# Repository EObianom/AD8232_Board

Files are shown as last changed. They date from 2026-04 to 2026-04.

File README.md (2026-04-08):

# AD8232_Board
AD8232 Mini ECG Breakout Board

A compact, production-ready ECG front-end built around the AD8232, designed for seamless integration into wearable and embedded systems.

Small in size, deliberate in design, and ready to manufacture.



## Overview

This project implements a highly miniaturised ECG acquisition circuit with a footprint of just 25mm × 17.7mm. It is engineered for space-constrained applications where traditional breakout boards fall short. Unlike conventional AD8232 modules, this design eliminates the bulky 3.5mm audio jack, enabling direct electrode interfacing and tighter system integration. The result is a clean, flexible, and deployment-ready biosignal front-end.

## Features
- Ultra-compact PCB (25mm × 17.7mm)
- Based on the AD8232 analog front-end for ECG signal conditioning
- Direct electrode interface (no audio jack) for reduced size and flexibility
- Carefully designed layout for low-noise signal acquisition
- Manufacturing-ready with full fabrication and assembly files

## Repository Contents
This repository provides a complete, production-ready hardware package:
1. Schematic
2. PCB Layout: Optimised layout focused on compactness.
3. Footprints: All components mapped to manufacturable, assembly-ready footprints.
4. Gerber Files: Fabrication files ready for immediate PCB manufacturing.
5. BOM (JLC Format): Bill of Materials.
6. CPL File: Pick-and-place file for automated component assembly.

## Getting Started

1. Review the schematic to understand the circuit design
2. Open the PCB layout in KiCad to inspect routing and placement
3. Use the Gerber files to order your PCB
4. Upload the BOM and CPL files to JLCPCB (or similar) for assembly

Once assembled, the board can be interfaced with a microcontroller ADC for signal capture and processing.

## Applications

- Wearable health monitoring devices
- Embedded ECG systems
- Biomedical research prototypes
- Low-power biosignal acquisition platforms

---

Disclaimer
This design is intended for research and development purposes only. It is not certified for medical or clinical use. This work is licensed under a Creative Commons Attribution-NonCommercial 4.0 International License.

Contributions and improvements are welcome.
Feel free to open an issue or submit a pull request.

Designed and developed by Ekenedirichukwu Obianom.

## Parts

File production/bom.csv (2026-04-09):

Designator | Footprint | Quantity | Value | LCSC Part #
C1 | 0603 | 1 | 1nF
C2 | 0603 | 1 | 10nF
C3 | 0603 | 1 | 1.5nF
C4, C5 | 0603 | 2 | 0.1uF
C6, C7 | 0603 | 2 | 0.33uF
D1 | 0603 | 1 | LED
J1, J2 | PinHeader_1x05_P2.54mm_Vertical | 2 | Conn_01x05_Pin
R1, R2 | 0805 | 2 | 180K
R10, R11, R12, R13, R14, R3, R4 | 0603 | 7 | 10M
R15 | 0805 | 1 | 470
R5 | 1206 | 1 | 360K
R6, R8, R9 | 0805 | 3 | 1M
R7 | 0603 | 1 | 100K
U1 | QFN-20-1EP_4x4mm_P0.5mm_EP2.6x2.6mm | 1 | AD8232

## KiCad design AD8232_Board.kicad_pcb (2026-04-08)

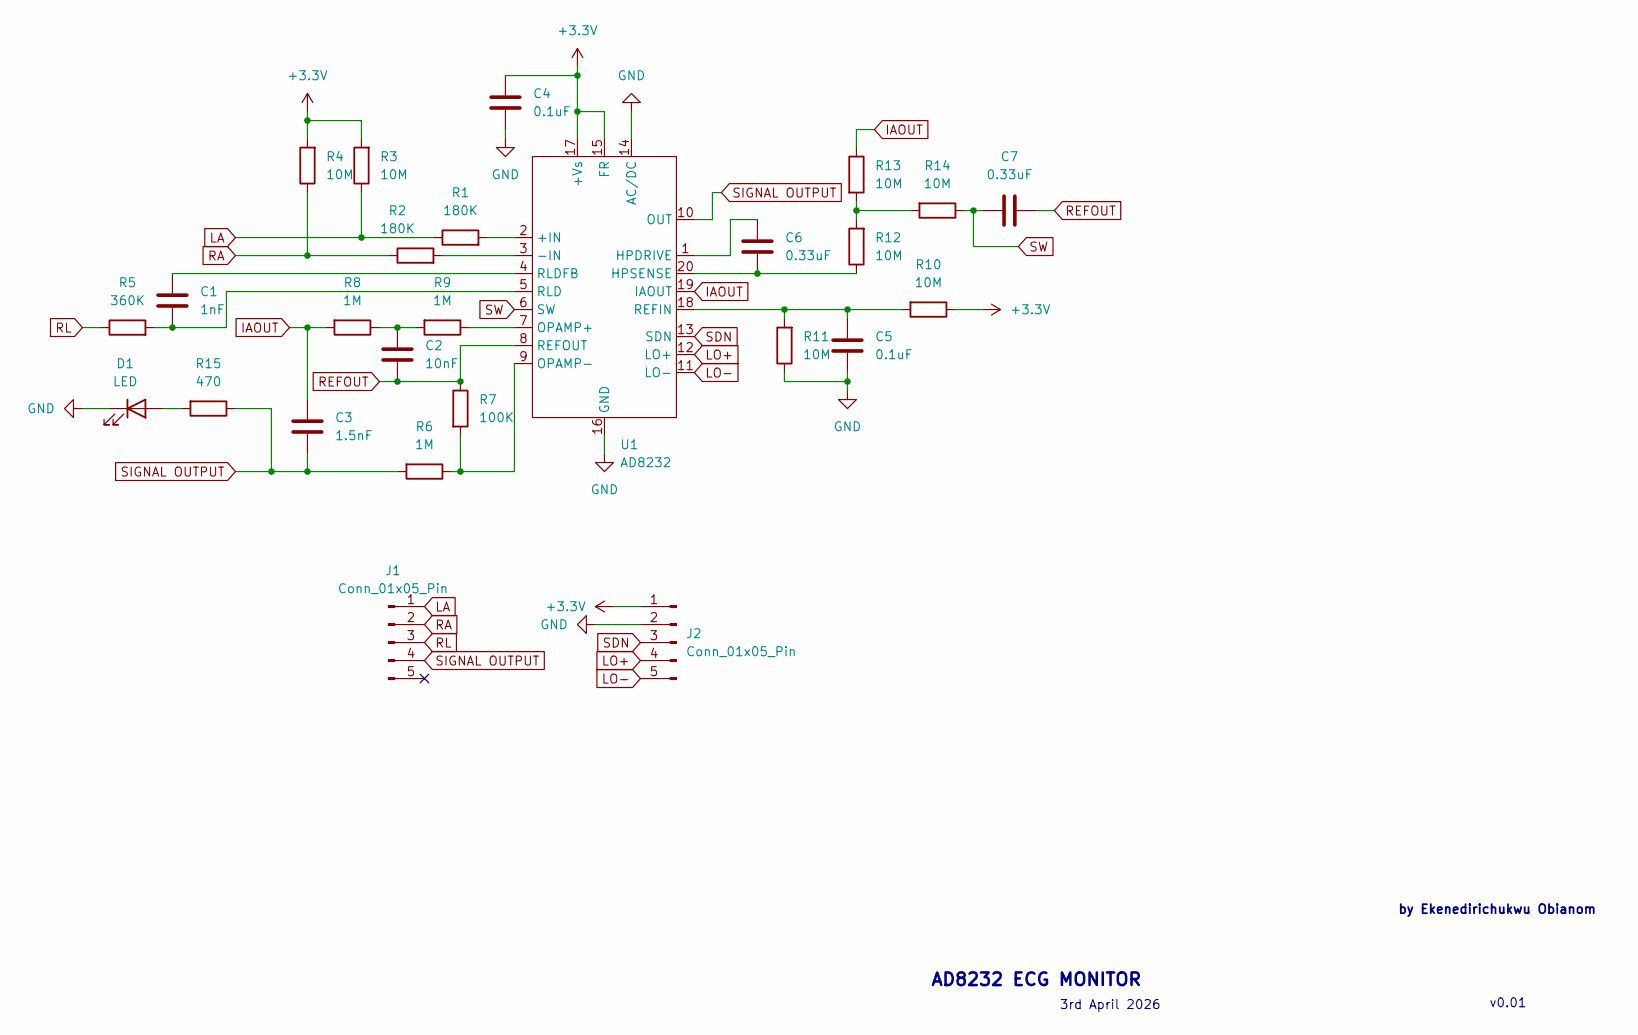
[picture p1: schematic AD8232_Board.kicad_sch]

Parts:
C1: 1nF; C_0603_1608Metric
C2: 10nF; C_0603_1608Metric
C3: 1.5nF; C_0603_1608Metric
C4, C5: 0.1uF; C_0603_1608Metric
C6, C7: 0.33uF; C_0603_1608Metric
D1: LED; LED_0603_1608Metric
J1, J2: Conn_01x05_Pin; PinHeader_1x05_P2.54mm_Vertical
R1, R2: 180K; R_0805_2012Metric
R3, R4, R10, R11, R12, R13, R14: 10M; R_0603_1608Metric
R5: 360K; R_1206_3216Metric
R6, R8, R9: 1M; R_0805_2012Metric
R7: 100K; R_0603_1608Metric
R15: 470; R_0805_2012Metric
U1: AD8232; QFN-20-1EP_4x4mm_P0.5mm_EP2.6x2.6mm

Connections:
+3.3V: C4.1, J2.1, R3.2, R4.2, R10.1, U1.15 (FR), U1.17 (+Vs)
GND: C4.2, C5.2, D1.1 (K), J2.2, R11.1, U1.14 (AC/DC), U1.16 (GND), U1.21 (GND)
IAOUT: C3.1, R8.2, R13.1, U1.19 (IAOUT)
LA: J1.1, R1.1, R3.1
LO+: J2.4, U1.12 (LO+)
LO-: J2.5, U1.11 (LO-)
unnamed: C2.1, R8.1, R9.2
unnamed: D1.2 (A), R15.2
unnamed: R12.2, R13.2, R14.2
unnamed: R1.2, U1.2 (+IN)
unnamed: R2.2, U1.3 (-IN)
unnamed: C6.1, U1.1 (HPDRIVE)
unnamed: C6.2, R12.1, U1.20 (HPSENSE)
unnamed: R9.1, U1.7 (OPAMP+)
unnamed: R6.1, R7.2, U1.9 (OPAMP-)
unnamed: C5.1, R10.2, R11.2, U1.18 (REFIN)
unnamed: C1.2, R5.2, U1.5 (RLD)
unnamed: C1.1, U1.4 (RLDFB)
RA: J1.2, R2.1, R4.1
REFOUT: C2.2, C7.2, R7.1, U1.8 (REFOUT)
RL: J1.3, R5.1
SDN: J2.3, U1.13 (SDN)
SIGNAL OUTPUT: C3.2, J1.4, R6.2, R15.1, U1.10 (OUT)
SW: C7.1, R14.1, U1.6 (SW)

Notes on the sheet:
by Ekenedirichukwu Obianom
3rd April 2026
v0.01
AD8232 ECG MONITOR

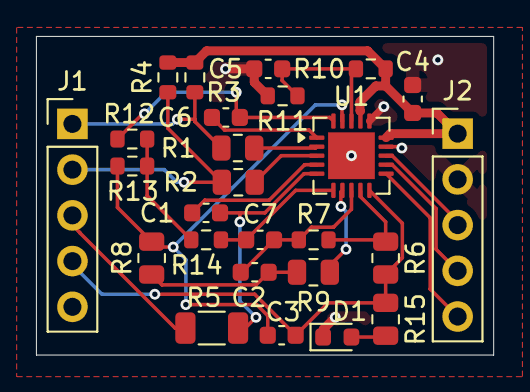
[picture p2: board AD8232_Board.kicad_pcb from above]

Board: 4 copper layers, 25.4 x 17.7 mm, 26 parts (0 on the bottom side), 24 nets.

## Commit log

2026-04-03 AD8232 Symbol added
    [AD8232_Board.kicad_pcb, AD8232_Board.kicad_sch]
2026-04-03 Library and Schematic Update
    - Updated the AD8232 Symbol to include 21 pins with the 21st auto connected to ground.
    - Completed the schematic for the board and attached footprints to them.
    [AD8232_Board.kicad_sch]
2026-04-03 Changed the footprint for AD8232
2026-04-03 PCB designed and Gerber files generated
    [AD8232_Board-B_Mask.gbs, AD8232_Board-B_Paste.gbp, AD8232_Board-B_SilkS.gbo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]
2026-04-03 light update to last commitment
    jclpcb bom and cpl included
    [AD8232_Board.kicad_pcb, AD8232_Board.kicad_sch]
2026-04-03 Enhance README with detailed project informatio
    Expanded the README to provide detailed information about the AD8232 Mini ECG Breakout Board, including features, repository contents, design notes, getting started instructions, applications, licens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
2026-04-08 Update silkscreen and soldermask settings
    Add multiple bottom silkscreen text labels (RL, AN, NC, LA, RA, 3.3, GND, SDN, LO+, LO-) to AD8232_Board.kicad_pcb and remove an explicit solder_mask_min_width entry. Adjust solder mask to copper clearance in AD8232_Board.kicad_pro from 0.0 to 0.005. Regenerate/update Gerber outputs (timestamps updated) and add the new bottom silkscreen Gerber (gerber/AD8232_Board-B_Silkscreen.gbo); updates to B_Mask and B_Paste files included as part of the export.
    [AD8232_Board-B_Mask.gbs, AD8232_Board-B_Paste.gbp, AD8232_Board-B_Silkscreen.gbo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]
2026-04-09 Add production BOM, designators, and positions
    Remove .gitignore rules that excluded exported BOM files (*.xml, *.csv) so production artifacts can be tracked. Add production/bom.csv (component list with quantities and LCSC part references), produ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
    [bom.csv, designators.csv, positions.csv]
